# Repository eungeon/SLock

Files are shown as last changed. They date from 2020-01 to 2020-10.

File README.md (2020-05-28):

# SLock
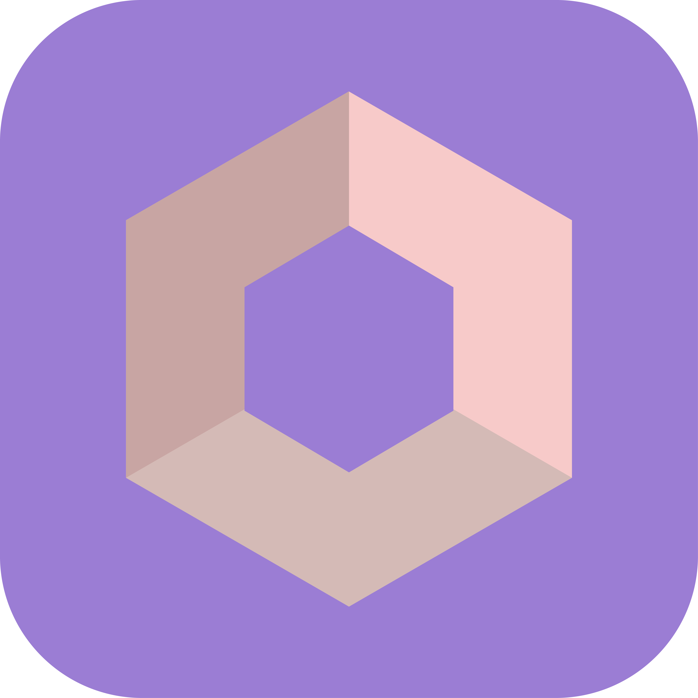
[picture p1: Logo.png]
<br/>

광주소프트웨어마이스터고등학교 기숙사 출입문 자동화 솔루션을 개발하는 저장소입니다.   

***
## 1. 시작하면서...
### 1.1. 개요
이 프로젝트는 광주소프트웨어마이스터고등학교에서 열리는 2019 GSM Festival에서 출품한 작품이며, 처음에는 프로토타입으로 제작하였다. 처음 프로토 타입은 회로구성을 만능기판에 납땝으로 제작하였으며, Autodesk사의 Fusion 360으로 하우징을 설계, 3D 프린터로 출력, 제작하였다.   
GSM Festival이 끝난 후, 좀 더 하드웨어를 높은 퀄리티로 만들어 보고자 PCB를 설계, 제작하여 좀더 소형화 시켜서 제작 후 본교 기숙사에 설치를 목표로 제작 할 예정이다.

### 1.2. Workflow
> GSM Festival을 진행하면서 제작한 흐름도이며, 업데이트가 필요하다.
> #### 1.2.1 System WorkFlow
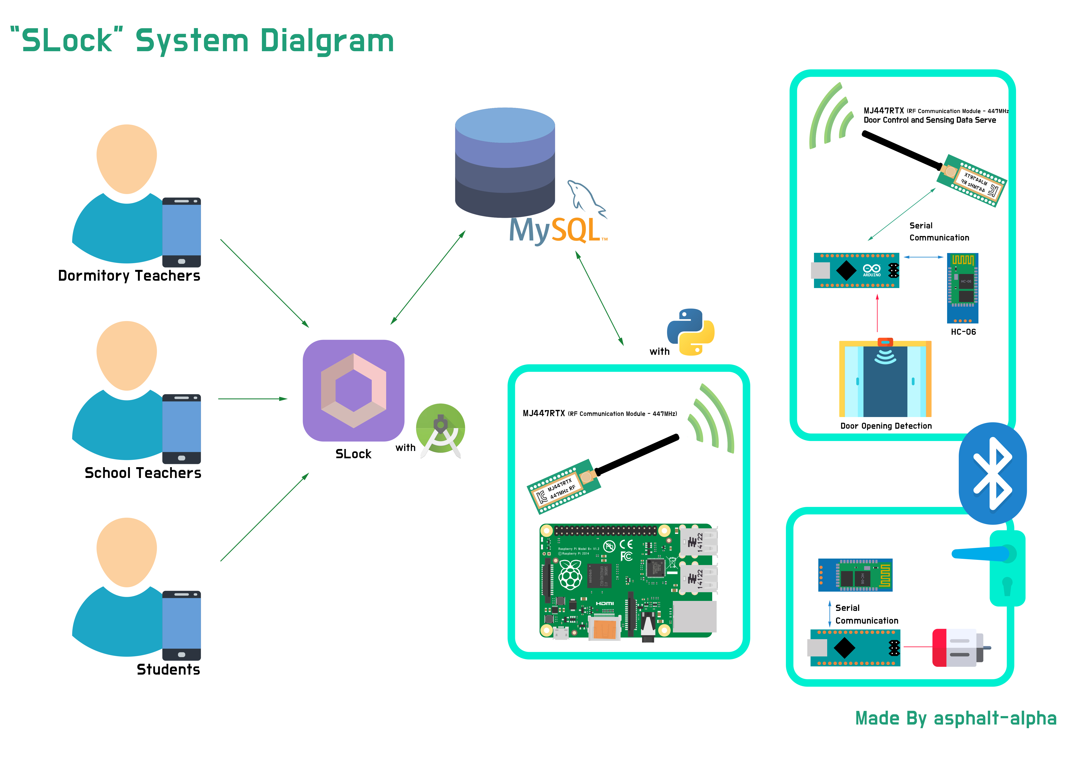
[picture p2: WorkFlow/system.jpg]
system
> 
> #### 1.2.2 Hardware WorkFlow
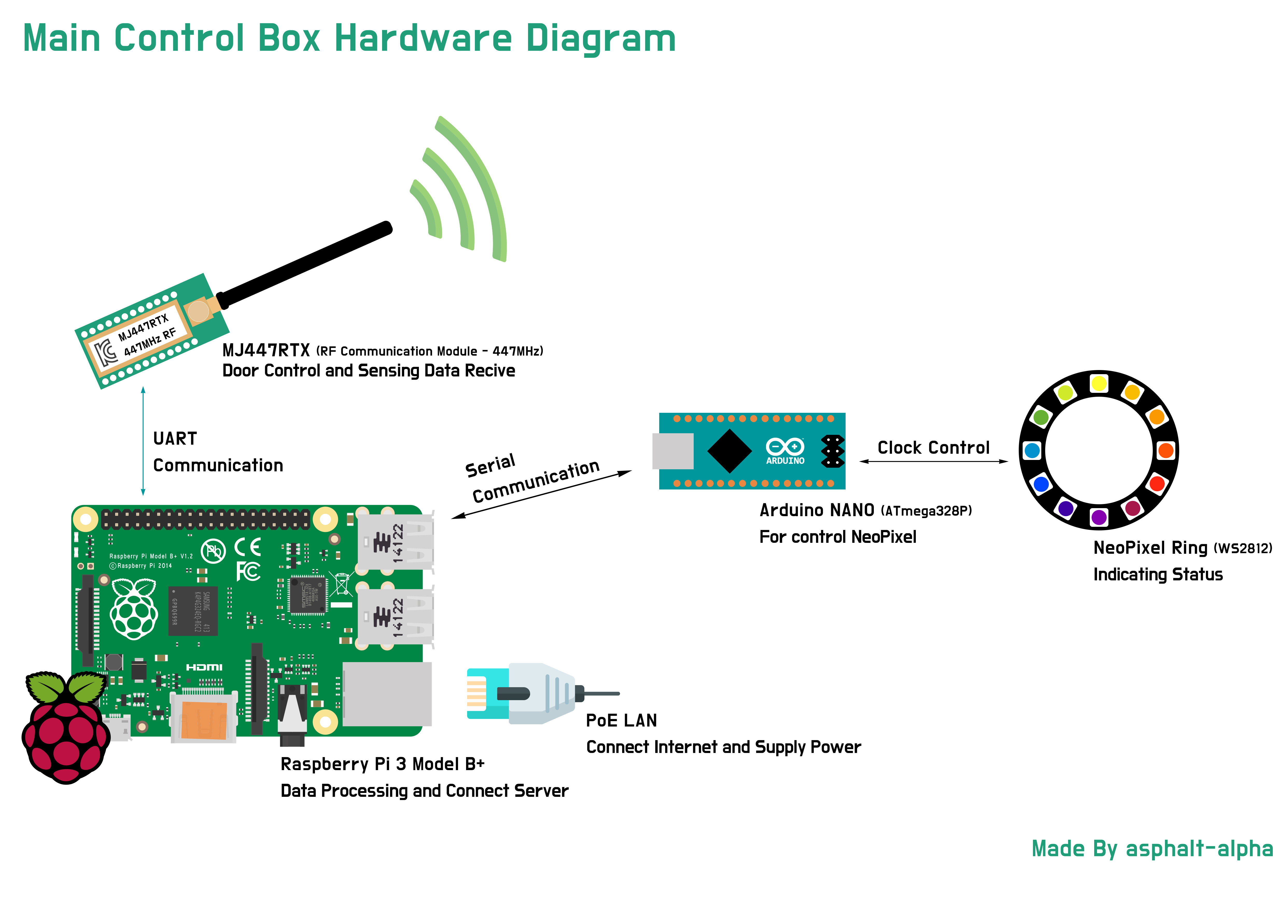
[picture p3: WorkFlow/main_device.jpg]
> 
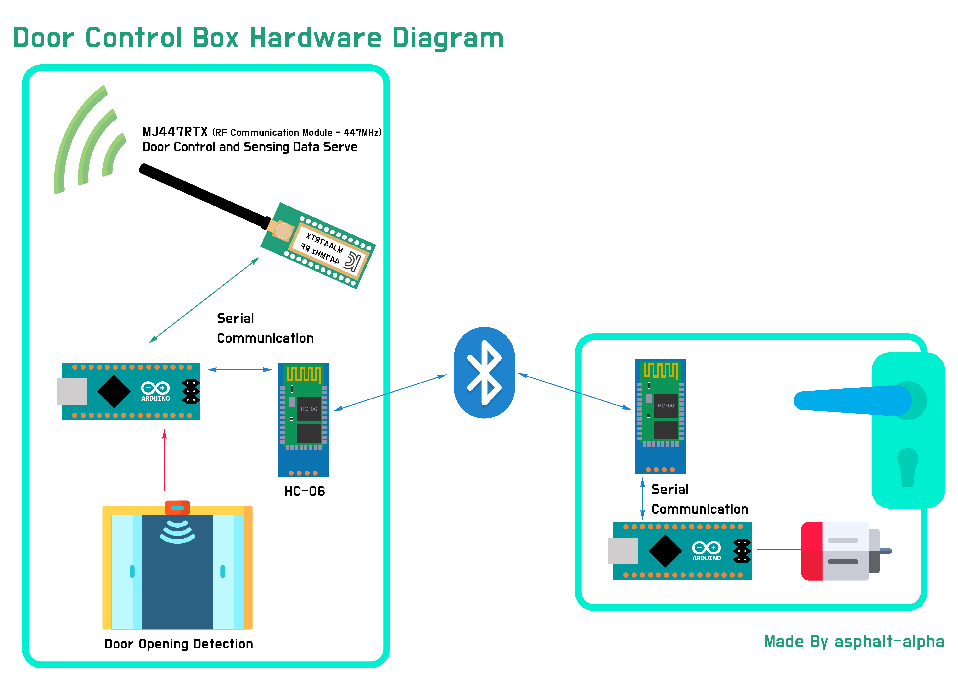
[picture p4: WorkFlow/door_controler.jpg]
> 
   
***
## 2. PCB Work
PCB 설계는 Autodesk사의 Eagle CAD를 사용하였으며, 아직 초보이기에 개선해야 할 부분이 많다.
### 2.1. Library
PCB 설계에 필요한 추가적인 User Library 를 사용하였으며, 본 저장소에 업로드되어 있다.
```
SLock\SLock_Circuit\libraries
```

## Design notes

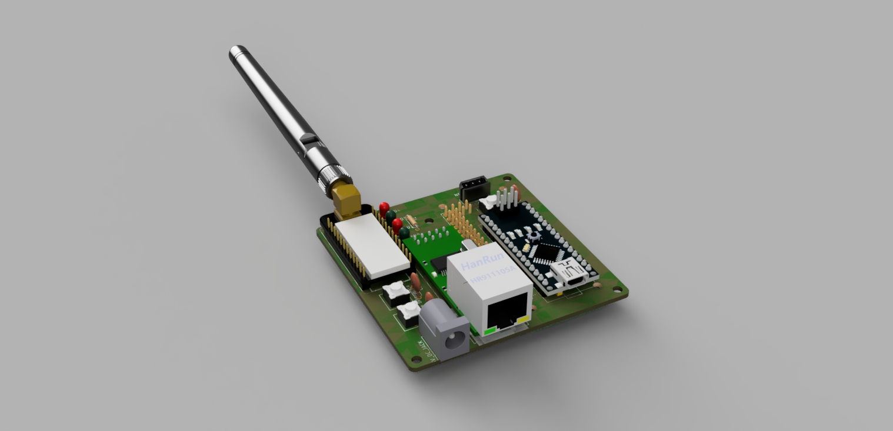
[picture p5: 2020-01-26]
SLock_Circuit/img/circuit_render_ver1.PNG

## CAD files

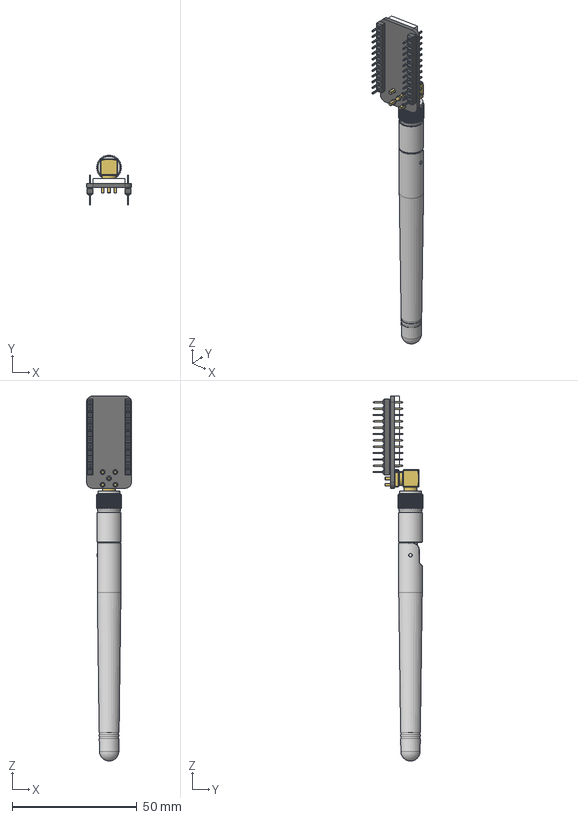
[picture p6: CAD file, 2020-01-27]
3D_Model/YUL262RTX/YUL262RTX.step
18.0 x 20.0 x 146.3 mm
SMA-angled
HDRV12W50P254_1X12_3048X254X700A x 2
Antenna base
Antenna top

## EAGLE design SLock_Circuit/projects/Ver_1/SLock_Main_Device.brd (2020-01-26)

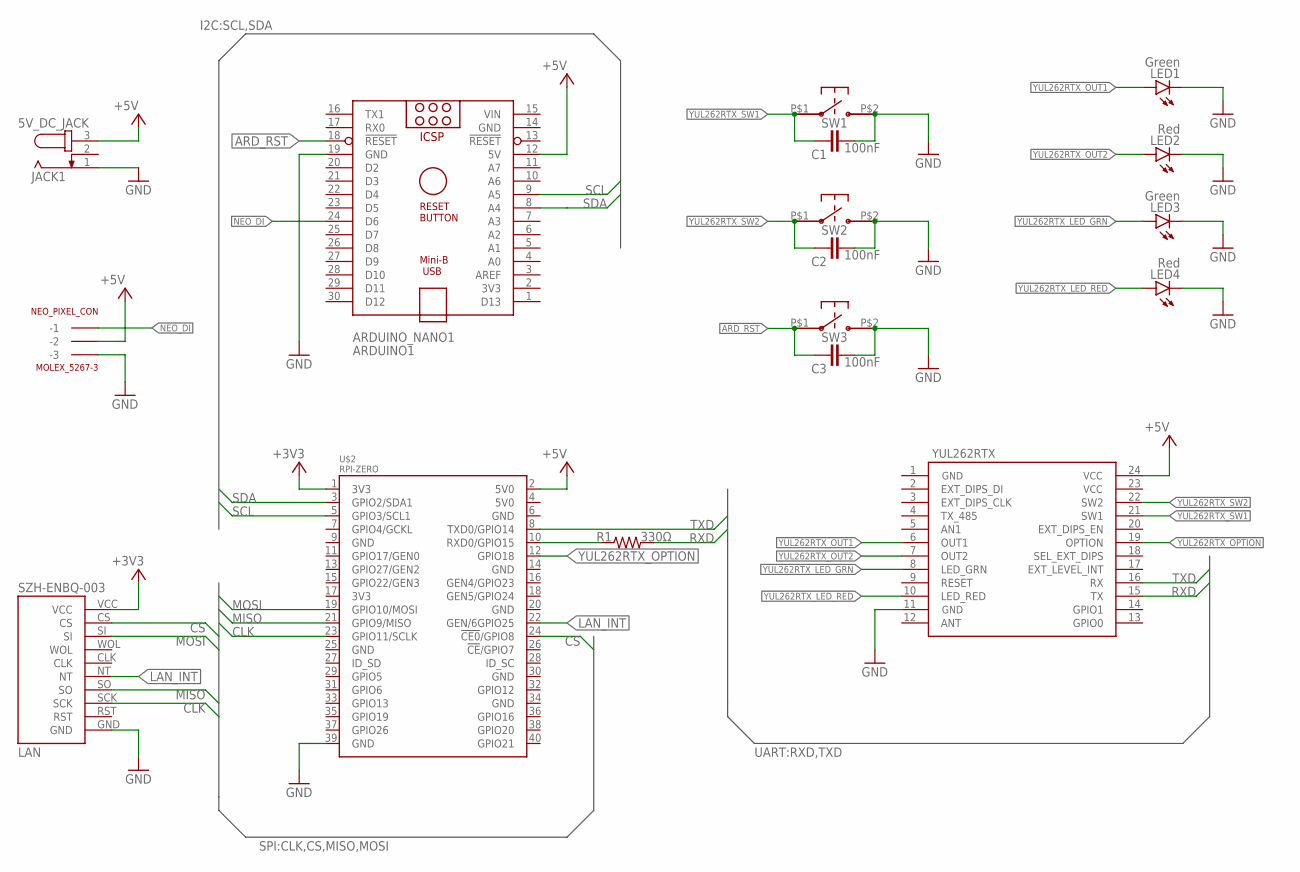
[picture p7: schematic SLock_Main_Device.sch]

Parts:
5V_DC_JACK: JACK1; SPC4077
ARDUINO_NANO1: ARDUINO1; ARDUINO_NANO
C1, C2, C3: 100nF; C050-024X044
LAN: SZH-ENBQ-003
LED1, LED3: Green; LED3MM
LED2, LED4: Red; LED3MM
NEO_PIXEL_CON: MOLEX_5267-3; 5267-3
R1: 330Ω; 0204/7
SW1, SW2, SW3: SKPDAMD010
U$2: RPI-ZERO; RASPBERRYPI_BASTELSTUBE_V13_RASPI_BOARD_B+_FULL
YUL262RTX: YUL262RTX; YUL262RXT_HOLE

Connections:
+3V3: LAN.VCC, U$2.1 (3V3)
+5V: 5V_DC_JACK.3, ARDUINO_NANO1.12 (5V), NEO_PIXEL_CON.P$2 (-2), U$2.2 (5V0), YUL262RTX.24 (VCC_2)
ARD_RST: ARDUINO_NANO1.18 (!RESET), C3.1, SW3.P$1
CLK: LAN.SCK, U$2.23 (GPIO11/SCLK)
CS: LAN.CS, U$2.24 (!CE0!/GPIO8)
GND: 5V_DC_JACK.1, ARDUINO_NANO1.14 (GND), ARDUINO_NANO1.19 (GND), C1.2, C2.2, C3.2, LAN.GND, LED1.K (C), LED2.K (C), LED3.K (C), LED4.K (C), NEO_PIXEL_CON.P$3 (-3), SW1.P$2, SW2.P$2, SW3.P$2, U$2.39 (GND), YUL262RTX.11 (GND_1)
GND_2: YUL262RTX.1 (GND_2)
LAN_INT: LAN.NT, U$2.22 (GEN/6GPIO25)
MISO: LAN.SO, U$2.21 (GPIO9/MISO)
MOSI: LAN.SI, U$2.19 (GPIO10/MOSI)
NEO_DI: ARDUINO_NANO1.24 (D6), NEO_PIXEL_CON.P$1 (-1)
RXD: R1.2, YUL262RTX.15 (TX)
RXD_INPUT: R1.1, U$2.10 (RXD0/GPIO15)
SCL: ARDUINO_NANO1.9 (A5), U$2.5 (GPIO3/SCL1)
SDA: ARDUINO_NANO1.8 (A4), U$2.3 (GPIO2/SDA1)
TXD: U$2.8 (TXD0/GPIO14), YUL262RTX.16 (RX)
VCC_1: YUL262RTX.23 (VCC_1)
VIN: ARDUINO_NANO1.15 (VIN)
YUL262RTX_LED_GRN: LED3.A, YUL262RTX.8 (LED_GRN)
YUL262RTX_LED_RED: LED4.A, YUL262RTX.10 (LED_RED)
YUL262RTX_OPTION: U$2.12 (GPIO18), YUL262RTX.19 (OPTION)
YUL262RTX_OUT1: LED1.A, YUL262RTX.6 (OUT1)
YUL262RTX_OUT2: LED2.A, YUL262RTX.7 (OUT2)
YUL262RTX_SW1: C1.1, SW1.P$1, YUL262RTX.21 (SW1)
YUL262RTX_SW2: C2.1, SW2.P$1, YUL262RTX.22 (SW2)

Board: 2 copper layers, 17 parts (0 on the bottom side), 22 nets, no tracks yet.

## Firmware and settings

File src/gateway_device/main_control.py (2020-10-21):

from time import sleep
import serial
import pymysql.cursors
import smbus
import signal
import sys

# define
SLAVE_ADDR = 0x10

SEN_ADDR = 0x10
LOCK_ADDR = 0x20

GET = 0x00
SET = 0x01
RES = 0x10

DOOR_SEN = 0x10
DOOR_LOCK = 0x20
EM_LOCK = 0x30

OPEN = 0x01
CLOSE = 0x00

# neopixel set with i2c
neoPixel = smbus.SMBus(1)

# MJ447RTX module set with UART
RF = serial.Serial("/dev/ttyAMA0", 9600, timeout = 1)

vals = [SEN_ADDR, 0x00, 0x10, 0x00]
oldRfData = bytes(1)
rfRx = []
mainDoor = 101

def SetColor(mode,r,g,b):
    neoPixel.write_i2c_block_data(SLAVE_ADDR,int(mode),[int(r),int(g),int(b)])

# ctrl+C signal Handler
def signal_handler(signal, frame):
    print('You pressed Ctrl+C!')
    print("Closing")
    SetDeviceConnection(0x00, False)
    conn.close()
    SetColor(0x00, 0, 0, 0)
    sys.exit(0)

def GetDB(table):
    rows = []
    try:
        with conn.cursor() as curs:
            conn.commit()
            selectSql = "SELECT * FROM " + table
            curs.execute(selectSql,)
            rows = curs.fetchall()
        #print(rows)
    finally:
        return rows

def GetDeviceStatus():
    rows = []
    try:
        with conn.cursor() as curs:
            selectSql = "SELECT * FROM Device"
            curs.execute(selectSql)
            rows = curs.fetchall()
        conn.commit() 
        #print(rows)
    finally:
        return rows

def GetStatus():
    try:
        with conn.cursor() as curs:
            conn.commit()
            selectSql = "SELECT * FROM door"
            curs.execute(selectSql)
            rows = curs.fetchall()
        print(rows)
    finally:
        return rows

def SetDeviceConnection(addr, status):
    try:
        with conn.cursor(pymysql.cursors.DictCursor) as curs:
            updateSql = "UPDATE Device SET connect=%s WHERE addr=%s"
            curs.execute(updateSql, (status,addr))
        conn.commit()
    finally:
        pass

def SetDoorSensor(d_num, d_flg):
    try:
        with conn.cursor(pymysql.cursors.DictCursor) as curs:
            updateSql = "UPDATE door SET d_flg=" + str(d_flg) + " WHERE d_num=" + str(d_num)
            updateSql = "UPDATE door SET d_flg=%s WHERE d_num=%s"
            print(curs.execute(updateSql, (d_flg, d_num)))
        conn.commit()
    finally:
        pass

try:
    
    signal.signal(signal.SIGINT, signal_handler)

    if __name__ == '__main__':
        # initializing Neopixel
        SetColor(0x01, 10, 0, 0)
        sleep(2)

        #connect to MySQL server
        conn = pymysql.connect(
            host='192.168.1.12',
            user='root',
            password='k06120393@',
            db='slock',
            charset='utf8')

        SetColor(0x00, 0, 0, 0)
        sleep(2)

        oldDoorStatus = []
        oldDeviceStatus = []

        SetDeviceConnection(0x00, True)     

        while True:
            # Door lock Setting
            doorStatus = GetDB('door')
            deviceStatus = GetDB('device')
            #print(doorStatus)
            for door in doorStatus:
                for device in deviceStatus:
                    if door[0] in device:
                        for i in range(3,5):
                            if device[i] == True:
                                if i == 3:
                                    controlDevice = DOOR_LOCK
                                elif i == 4:
                                    controlDevice = EM_LOCK
                                else:
                                    continue

                                RF.write(bytearray([device[0], SET, controlDevice, door[2]]))
                                print("command : " + '0x'+'{0:02X}'.format(device[0]),'0x'+'{0:02X}'.format(SET),'0x'+'{0:02X}'.format(controlDevice),'0x'+'{0:02X}'.format(door[2]))

                                while RF.readable():
                                    del rfRx[0:]
                                    for i in range(0,4):
                                        rfRx.append(RF.read())
                                    #print(rfRx)

                                    if rfRx[0] != '':
                                        rfData = bytearray(rfRx)
                                        print("receive : " + '0x'+'{0:02X}'.format(rfData[0]),'0x'+'{0:02X}'.format(rfData[1]),'0x'+'{0:02X}'.format(rfData[2]),'0x'+'{0:02X}'.format(rfData[3]))
                                        if rfData == bytearray([device[0], RES, controlDevice, door[2]]):
                                            SetDeviceConnection(device[0], True)
                                        else:
                                            print("communication Error")
                                            SetDeviceConnection(device[0], False)
                                    else:
                                        print("not communicate")
                                        SetDeviceConnection(device[0], False)
                                    break
            
            for device in deviceStatus:
                if device[2] == True:
                    RF.write(bytearray([device[0], GET, DOOR_SEN, 0x00]))
                    print("command : " + '0x'+'{0:02X}'.format(device[0]),'0x'+'{0:02X}'.format(GET),'0x'+'{0:02X}'.format(DOOR_SEN),'0x'+'{0:02X}'.format(0))

                    while RF.readable():
                        del rfRx[0:]
                        for i in range(0,4):
                            rfRx.append(RF.read())
                        #print(rfRx)

                        if rfRx[0] != '':
                            rfData = bytearray(rfRx)
                            print("receive : " + '0x'+'{0:02X}'.format(rfData[0]),'0x'+'{0:02X}'.format(rfData[1]),'0x'+'{0:02X}'.format(rfData[2]),'0x'+'{0:02X}'.format(rfData[3]))
                            if rfData[:3] == bytearray([device[0], RES, DOOR_SEN]):
                                SetDeviceConnection(device[0], True)
                                print(rfData[3] == CLOSE and "Close" or "Open")
                                if rfData[3] == CLOSE:
                                    SetDoorSensor(device[1], CLOSE)
                                    if device[1] == mainDoor and oldRfData != rfData[3]:
                                        SetColor(0x00, 0, 200, 0)
                                        oldRfData = rfData[3]        
                                elif rfData[3] == OPEN:
                                    SetDoorSensor(device[1], OPEN)
                                    if device[1] == mainDoor and oldRfData != rfData[3]:
                                        SetColor(0x00, 200, 0, 0)
                                        oldRfData = rfData[3]
                                else:
                                    pass
                            else:
                                print("communication Error")
                                SetDeviceConnection(device[0], False)
                                if device[1] == mainDoor:
                                    SetColor(0x00, 200, 100, 0)
                                    oldRfData = 0xFF
                                    
                        else:
                            print("not communicate")
                            SetDeviceConnection(device[0], False)
                            if device[1] == mainDoor:
                                SetColor(0x00, 200, 100, 0)
                                oldRfData = 0xFF
                        break

except Exception as e : 
    print(str(e)) 
    pass

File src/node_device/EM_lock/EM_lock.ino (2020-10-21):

#include <SoftwareSerial.h>

#define ADDR 0x20

#define GET 0x00
#define SET 0x01
#define RES 0x10

#define DOOR_SEN 0x10
#define DOOR_LOCK 0x20
#define EM_LOCK 0x30

#define OPEN 0x01
#define CLOSE 0x00

SoftwareSerial BT(2, 3); // TX, RX
SoftwareSerial RF(4, 5); // TX, RX

void RF_Response(unsigned char* tx, unsigned char act,unsigned char ctrl,unsigned char val);

int emLock = 6;
unsigned char RF_rx[4];
bool RF_en = false;

void setup() {
  // put your setup code here, to run once:
  Serial.begin(9600);
  BT.begin(9600);
  RF.begin(9600);

  pinMode(emLock,OUTPUT);
}

int action=0, control=0, value=0;

void loop() {
  if(RF.available()){
    Serial.print("MJ447RTX : ");
    RF.readBytes(RF_rx,4);
    RF_en = true;
  }
  if(Serial.available()){
    BT.write(Serial.read());
  }
  if(BT.available()){
    Serial.write(BT.read());
  }

  if(RF_en){
    for(int i=0; i<4; i++){
      Serial.print("0x");
      Serial.print(RF_rx[i],16);  
      Serial.print(' ');
    }
    Serial.println(" ");
    
    //Serial.println(RF_rx[0]);
    if(RF_rx[0] == ADDR){
      Serial.println("Receive");
      action = RF_rx[1];
      control = RF_rx[2];
      value = RF_rx[3];

      unsigned char buf[4];
      RF_Response(buf, RF_rx[1],RF_rx[2],RF_rx[3]);
      //delay(5000);
      RF.write(buf,4);
      Serial.write(buf,4);
      Serial.println("");
      for(int i=0; i<4; i++){
        Serial.print("0x");
        Serial.print(buf[i],16); 
        Serial.print(' '); 
      }
      Serial.println("");
    }
    memset(RF_rx, 0, 4);
    RF_en = false;
  }

}

void RF_Response(unsigned char* tx, unsigned char act,unsigned char ctrl,unsigned char val){
  tx[0] = ADDR;
  tx[1] = RES;
  tx[2] = ctrl;
  
  if(act == GET){
    switch(ctrl & 0xF0){
        case DOOR_SEN:
        case DOOR_LOCK:
          tx[3] = 0xFF;
          break;
          
        case EM_LOCK:
          if(digitalRead(emLock) == HIGH) tx[3] = CLOSE;
          else tx[3] = OPEN;
          break;
          
        default:
          tx[3] = 0xFF;
          break;
    }
  }
  else if(act == SET){
    switch(ctrl & 0xF0){
      case DOOR_LOCK:
        tx[3] = 0xFF;
        break;
        
      case EM_LOCK:
        if(val == OPEN) digitalWrite(emLock, LOW);
        else if(val == CLOSE) digitalWrite(emLock, HIGH);
        tx[3] = val;
        break;
        
      case DOOR_SEN:
      default:
        tx[3] = 0xFF;
        break;
    }
  }
  else{
    tx[3] = 0xFF;
  }
}

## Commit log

2020-01-24 [Added] circuit file
    전에 했던 파일 커밋
    [SLock_Main_Device.brd, SLock_Main_Device.sch]
2020-01-24 [Changed] Folder structure
    이글캐드 프로젝트 폴더 정리화 및 프로젝트 연결
    [SLock_Main_Device.brd, SLock_Main_Device.sch]
2020-01-26 [Updated] Main_Device circuit
    위치변경 및 보드 임시 Export
    [SLock_Main_Device.brd]
2020-01-26 [Added] Main_device circuit Render image
    임시 Export 한 pcb로 가조립
2020-01-27 [Added] YUL262RTX 3D file
    라디오리써치社의 YUL262RTX RF 모듈을 3D file 로 제작
    각각 step file, fbx file로 Export.
    [YUL262RTX.step]
2020-01-27 [Added] old work flow image
    전에 제작한 워크플로우 및 로고 업로드.
    교체 예정.
2020-01-27 [Changed] flow image rename
    이미지 이름을 좀더 간결하게 수정
2020-01-27 Update README.md
    PCB 부분 설명 추가
2020-01-29 [Updated] gitignore
    맥에서 생성되는 .DS_Store 파일을 gitignore에 추가. 아직 해도 되는지 알 수 없지만 추가함. 확인 필요
2020-10-21 [Added] gateway LED control src
